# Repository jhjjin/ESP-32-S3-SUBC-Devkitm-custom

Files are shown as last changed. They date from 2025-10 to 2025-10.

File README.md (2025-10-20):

# ⚡ ESP32-S3 USB-C DevkitM Custom Board  
Custom **ESP32-S3 (ESP32-S3-MINI-1-N8)** development board designed from scratch in **Altium Designer 25.8.1**, featuring USB-C connectivity, FT231X UART bridge, ESD protection, and a 4-layer impedance-controlled PCB verified for **JLCPCB** manufacturing standards.  

---

## 🧩 Overview

- A fully custom ESP32-S3-MINI-1-N8 dev board built as a learning and portfolio project.  
- Designed and validated for manufacturability, signal integrity, and professional layout discipline.
--- 
Key specs:
- ✅ USB-C interface (Molex I/O connector)
- ✅ FTDI FT231XQ-R USB-UART bridge  
- ✅ Littelfuse AQ3045-01ETG (ESD/TVS Protection)
- ✅ Low-dropout regulator with ESR 20 µF input cap  
- ✅ Differential pair routing for USB 2.0  
- ✅ Variant setup for NF (DNP) parts  
- ✅ JLCPCB 4-Layer Stackup (JLC04161H-3313)

---

## 🛠️ Design Tools & Environment
| Tool | Version | Purpose |
|---|---|---|
| **Altium Designer** | 25.8.1 | Schematic, PCB, DRC |
| **ViewMate** | 11.14 | Gerber Verification |
| **SnapEDA / 3D ContentCentral** | – | STEP Models / Footprints |
| **JLCPCB Calculator** | – | Impedance Matching |

---

## 📐 PCB Stackup
| Layer | Type | Notes |
|---|---|---|
| **L1** | Signal (Top) | High-speed USB / MCU routing |
| **L2** | GND Plane | Solid ground reference |
| **L3** | Power Plane | +3V3 / +5V islands |
| **L4** | Signal (Bottom) | GPIO, UART, LED, test traces |

📏 **Stackup:** JLC04161H-3313 (1.6 mm FR-4)  
🎯 **USB 90 Ω diff / 50 Ω single** controlled impedance

---

## ⚙️ Main Components

| Function | Part | Supplier | LCSC Part No |
|---|---|---|---|
| MCU | ESP32-S3-MINI-1-N8 | ESPRESSIF | **C2913206** |
| USB-UART | FT231XQ-R | FTDI | **C3212159** |
| ESD Protection | AQ3045-01ETG | Littelfuse | **C3710326** |
| Regulator | TL1963A-33DCYR (3.3 V LDO) | Texas Instruments | **C1812626** |
| LED (Green) | VLMG1500-GS08 | Vishay | **C5111404** |
| LED (Red) | VLMS1500-GS08 | Vishay | **C5111370** |
| Cap (100 nF, 50 V) | CL05B104KB54PNC | Samsung | **C307331** |
| Cap (4.7 µF, 16 V) | CL05A475MO5NUNC | Samsung | **C318563** |
| Resistor (1 kΩ) | RC0402FR-071KL | Yageo | **C106023** |
| Resistor (4.7 kΩ) | RC0402FR-074K7L | Yageo | **C105871** |
| Resistor (5.1 kΩ) | RC0402FR-075K1L | Yageo | **C1447745** |
| Resistor (10 kΩ) | RC0402FR-0710KL | Yageo | **C1444807** |
| Jumper Header (2-pin) | FTS-102-01-F-S | Samtec | **C6045317** |
| Jumper Header (3-pin) | FTS-103-01-F-S | Samtec | **C3333578** |
| Shunt | M50-1920005 | Harwin | **C6985646** |
| USB-C Connector | 217179-0001 | Molex | **C3197684** |
| Transistor | SS8050-G | Comchip | **C21406** |
| Diode (TVS) | AQ3045-01ETG | Littelfuse | **C3710326** |

---

## 🧭 Schematic Overview
```
USB-C (Power / Data)
     │
[FT231X UART Bridge]
     │
ESP32-S3-MINI-1-N8 ←→ Boot / Reset / LEDs / Headers
     │
[LDO Regulator]
     │
+3V3 / +5V
```
---

---

## 🔍 Build Notes & Troubleshooting

### ⚡ Common Design Challenges
| Issue | Cause | Fix |
|---|---|-----|
| GND recognized as +3V3 | Power port misconnection | Disconnect and redraw from `GND` port |
| FTDI clearance too tight | Dense routing | Define `Room('FTDI')` and set clearance 6 mil |
| USB diff pair warning | Width/gap mismatch | Apply `DIFF90` rule (6.03 mil / 8 mil) |
| “Footprint not found” (J6) | Library mismatch | Re-link footprint and `Design ▸ Update PCB` |
| Silk-to-mask errors | Fabrication tolerance | Set `Silk to Mask = 5 mil` per JLC spec |
| 3D misalignment | STEP origin offset | `3D Body ▸ Align Face with Body` → `Set Reference Center` |

---

### 🧱 PCB Layout Highlights
- **Via:** Ø 24 mil / hole 12 mil  
- **USB diff pairs:** 6.03 mil width, 8 mil spacing  
- **Power tracks:** 15 mil width  
- **GND stitching vias:** around USB and RF areas  
- **Polygon pour:** direct connect for +3V3, thermal for GND  

## 🖼️ Hardware Preview

<p align="center">
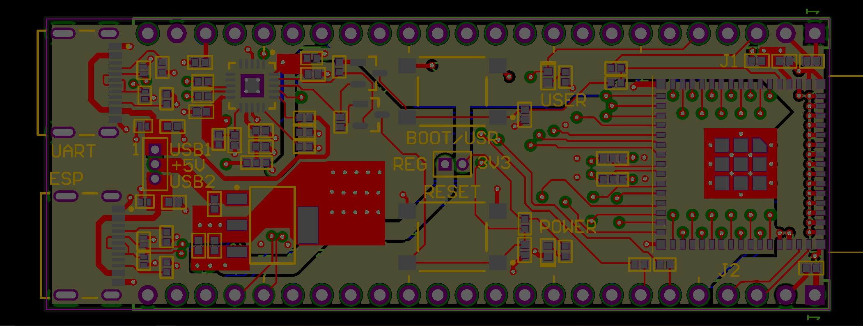
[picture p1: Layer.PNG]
PCB Layout Overview
  
</p>

| 3D Front | 3D Back |
|:---:|:---:|
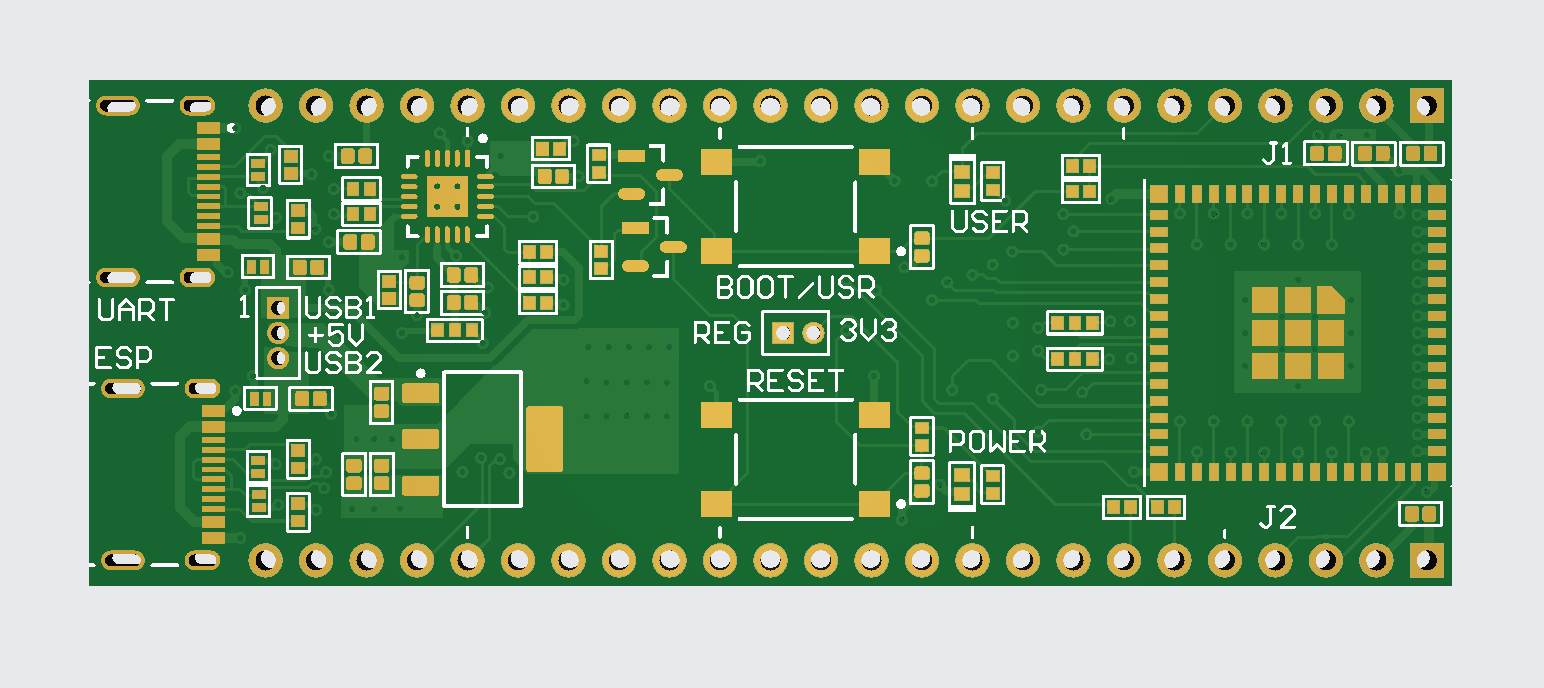
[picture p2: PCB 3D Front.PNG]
3D Front View
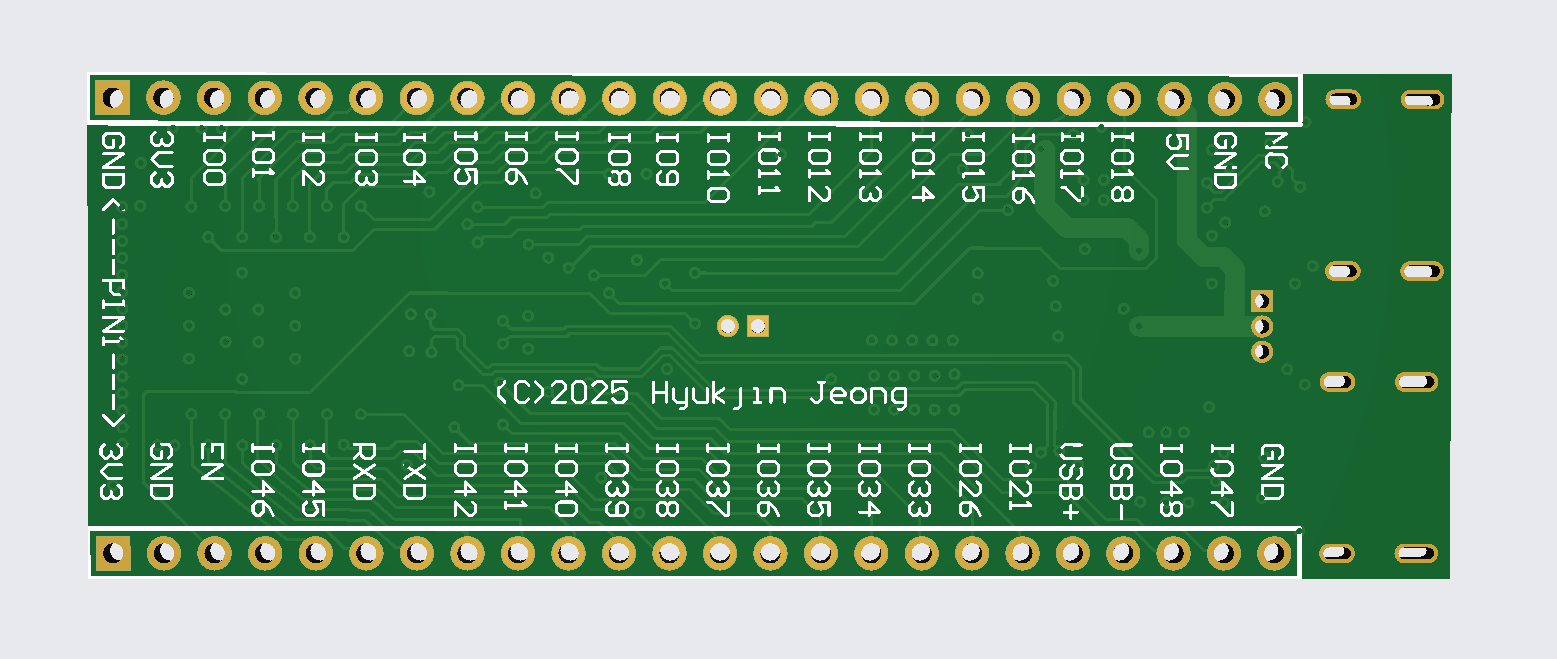
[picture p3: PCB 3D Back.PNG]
3D Back View
|  |  |

> **Figure:** PCB layout (Layer) and 3D render previews for the custom ESP32-S3 USB-C DevkitM board.

---
---

## 📦 Fabrication Outputs

The project includes full manufacturing and assembly documentation for **JLCPCB** and other PCB assembly vendors.

### 🧾 Bill of Materials (BOM)
| Field | Example |
|:---|:---|
| **Component Count** | 38 unique parts (Samsung, Yageo, FTDI, Espressif, TI, etc.) |
| **Main ICs** | ESP32-S3-MINI-1-N8, FT231XQ-R, TL1963A-33DCYR |
| **Passive Parts** | 0402 Capacitors & Resistors (Yageo / Samsung) |
| **ESD / Protection** | Littelfuse AQ3045-01ETG |
| **Connectors** | Molex USB-C (217179-0001), Samtec Headers (FTS-103-01-F-S / FTS-102-01-F-S) |
| **LEDs** | Vishay VLMG1500-GS08 (Green), VLMS1500-GS08 (Red) |
| **Supplier Integration** | LCSC + DigiKey references with cross-checked MPNs |

🧩 The BOM is exported directly from **Altium Designer 25.8.1**, containing:
- Description, Designator, Footprint, Quantity, Manufacturer, MPN, LCSC / DigiKey number  
- All capacitors and resistors use **0402 metric footprint**  
- Variant configuration for **NF (Not Fitted)** parts included  

---

### 📍 Pick & Place (Component Position)
| Field | Example Data |
|:---|:---|
| **Coordinates** | X/Y in mils (Altium standard) |
| **Rotation** | 0°, 90°, 180°, 270° |
| **Layers** | TopLayer / BottomLayer |
| **Included Fields** | Designator, Comment, Layer, Footprint, Center-X, Center-Y, Rotation, Description |

---
## 🧠 Learnings & Focus

- Real-world PCB stackup and impedance control

- Rule-based design approach (Component, Clearance, DiffPairs)

- Synchronizing schematic ↔ PCB libraries

- DRC-driven layout verification

- Preparation of Gerber, BOM, Pick & Place, and PDF documentation

---

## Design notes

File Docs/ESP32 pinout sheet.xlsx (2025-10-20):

1 | GND_01
2 | GND_02
3 | 3V3
4 | GPIO0/RTC_GPIO0
5 | GPIO1/RTC_GPIO1/TOUCH1/ADC1_CH0
6 | GPIO2/RTC_GPIO2/TOUCH2/ADC1_CH1
7 | GPIO3/RTC_GPIO3/TOUCH3/ADC1_CH2
8 | GPIO4/RTC_GPIO4/TOUCH4/ADC1_CH3
9 | GPIO5/RTC_GPIO5/TOUCH5/ADC1_CH4
10 | GPIO6/RTC_GPIO6/TOUCH6/ADC1_CH5
11 | GPIO7/RTC_GPIO7/TOUCH7/ADC1_CH6
12 | GPIO8/RTC_GPIO8/TOUCH8/ADC1_CH7/SUBSPICS1
13 | GPIO9/RTC_GPIO9/TOUCH9/ADC1_CH8/FSPIHD/SUBSPIHD
14 | GPIO10/RTC_GPIO10/TOUCH10/ADC1_CH9/FSPICS0/FSPIIO4/SUBSPICS0
15 | GPIO11/RTC_GPIO11/TOUCH11/ADC2_CH0/FSPID/FSPIIO5/SUBSPID
16 | GPIO12/RTC_GPIO12/TOUCH12/ADC2_CH1/FSPICLK/FSPIIO6/SUBSPICLK
17 | GPIO13/RTC_GPIO13/TOUCH13/ADC2_CH2/FSPIQ/FSPIIO7/SUBSPIQ
18 | GPIO14/RTC_GPIO14/TOUCH14/ADC2_CH3/FSPIWP/FSPIDQS/SUBSPIWP
19 | GPIO15/RTC_GPIO15/U0RTS/ADC2_CH4/XTAL_32K_P
20 | GPIO16/RTC_GPIO16/U0CTS/ADC2_CH5/XTAL_32K_N
21 | GPIO17/RTC_GPIO17/U1TXD/ADC2_CH6
22 | GPIO18/RTC_GPIO18/U1RXD/ADC2_CH7/CLK_OUT3
23 | USB_D-/RTC_GPIO19/GPIO19/U1RTS/ADC2_CH8/CLK_OUT2
24 | USB_D+/RTC_GPIO20/GPIO20/U1CTS/ADC2_CH9/CLK_OUT1
25 | GPIO21/RTC_GPIO21
26 | GPIO26/SPICS1
27 | GPIO47/SPICLK_P_DIFF/SUBSPICLK_P_DIFF
28 | GPIO33/SPIIO4/FSPIHD/SUBSPIHD
29 | GPIO34/SPIIO5/FSPICS0/SUBSPICS0
30 | GPIO48/SPICLK_N_DIFF/SUBSPICLK_N_DIFF
31 | GPIO35/SPIIO6/FSPID/SUBSPID
32 | GPIO36/SPIIO7/FSPICLK/SUBSPICLK
33 | GPIO37/SPIDQS/FSPIQ/SUBSPIQ
34 | GPIO38/FSPIWP/SUBSPIWP
35 | MTCK/GPIO39/CLK_OUT3/SUBSPICS1
36 | MTDO/GPIO40/CLK_OUT2
37 | MTDI/GPIO41/CLK_OUT1
38 | MTMS/GPIO42
39 | U0TXD/GPIO43/CLK_OUT1
40 | U0RXD/GPIO44/CLK_OUT2
41 | GPIO45
42 | GND
43 | GND
44 | GPIO46
45 | EN
46 | GND_46
47 | GND_47
48 | GND_48
49 | GND_49
50 | GND_50
51 | GND_51
52 | GND_52
53 | GND_53
54 | GND_54
55 | GND_55
56 | GND_56
57 | GND_57
58 | GND_58
59 | GND_59
60 | GND_60
61 | GND_61
62 | GND_62
63 | GND_63
64 | GND_64
65 | GND_65
66 | GND_66
67 | GND_67
68 | GND_68
69 | GND_69
70 | GND_70
71 | GND_71
72 | GND_72
73 | GND_73

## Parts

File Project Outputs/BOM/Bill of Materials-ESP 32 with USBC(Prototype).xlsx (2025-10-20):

Comment | Description | Designator | Footprint | LibRef | Quantity | LCSC Part Number | Manufacturer | Manufacturer Part Number | Supplier | Supplier Part Number
100nF, 50V | CAP CER 0.1UF 50V X7R 0402 | C1, C3, C4, C5, C6, C8, C9, C10, C15 | CAPC1005X65N | CL05B104KB54PNC | 9 | C307331 | Samsung Electro-Mechanics | CL05B104KB54PNC | DigiKey | 1276-CL05B104KB54PNCCT-ND
4u7, 16V | CAP CER 4.7UF 16V X5R 0402 | C2, C11 | CAPC1005X65N | CL05A475MO5NUNC | 2 | C318563 | Samsung Electro-Mechanics | CL05A475MO5NUNC | DigiKey | 1276-6836-1-ND
10uF, 10V | CAP CER 10UF 10V X5R 0402 | C12, C13, C14 | CAPC1005X65N | CL05A106MP8NUB8 | 3 | C307415 | Samsung Electro-Mechanics | CL05A106MP8NUB8 | DigiKey | 1276-6830-6-ND
1uF, 35V | CAP CER 1UF 35V X5R 0402 | C16 | CAPC1005X65N | CL05A105KL5NRNC | 1 | C307413 | Samsung Electro-Mechanics | CL05A105KL5NRNC | DigiKey | 1276-6796-6-ND
GREEN | LED YLW-GRN 0402 SMD | D1 | LED0402G | VLMG1500-GS08 | 1 | C511404 | Vishay | VLMG1500-GS08 | DigiKey | VLMG1500-GS08CT-ND
RED | LED RED 0402 SMD | D2 | LED0402R | VLMS1500-GS08 | 1 | C511370 | Vishay | VLMS1500-GS08 | DigiKey | VLMS1500-GS08CT-ND
AQ3045-01ETG | TVS DIODE 5.3VWM 12VC SOD882 | D3, D4, D5, D6, D7, D8 | SOD882 | AQ3045-01ETG | 6 | C3710326 | Littelfuse | AQ3045-01ETG | DigiKey | F9321CT-ND
22-28-4245 | CONN HEADER VERT 24POS 2.54MM | J1, J2 | HDR_1X24_2.54MM | 22-28-4245 | 2 | C7145888 | Molex | 22-28-4245 | DigiKey | 900-0022284245-ND
217179-0001 | CONN RCP USB2.0 TYP C 24P SMD RA | J3, J4 | FP-2171790001-MFG | 217179-0001 | 2 | C3197684 | Molex | 217179-0001 | DigiKey | 900-2171790001CT-ND
FTS-103-01-F-S | CONN HEADER VERT 3POS 1.27MM | J5 | HDR_1X3_1.27MM | FTS-103-01-F-S | 1 | C3333578 | Samtec | FTS-103-01-F-S | DigiKey | 612-FTS-103-01-F-S-ND
FTS-102-01-F-S | CONN HEADER VERT 2POS 1.27MM | J6 | HDR_1X2_1.27MM | FTS-102-01-F-S | 1 | C6045317 | Samtec | FTS-102-01-F-S | DigiKey | SAM15176-ND
M50-1920005 | CONN SHUNT 1.27MM RED | LINK1, LINK2 |  | M50-1920005 | 2 | C6985646 | Harwin | M50-1920005 | DigiKey | 952-1727-ND
SS8050-G | TRANS NPN 25V 1.5A SOT-23-3 | Q1, Q2 | FP-SS8050-G-IPC_B | SS8050-G | 2 | C164886 | Comchip | SS8050-G | DigiKey | 641-1790-1-ND
0R | RES 0 OHM JUMPER 1/16W 0402 | R1, R5, R8, R19, R20, R23, R24 | RESC1005X37N | RC0402JR-070RL | 7 | C60485 | Yageo Group | RC0402JR-070RL | DigiKey | 311-0.0JRCT-ND
1K | RES 1K OHM 1% 1/16W 0402 | R3, R4 | RESC1005X37N | RC0402FR-0710KL | 2 | C106235 | Yageo Group | RC0402FR-0710KL | DigiKey | 311-10.0KLRCT-ND
27R | RES 27 OHM 1% 1/16W 0402 | R6, R7, R21, R22 | RESC1005X37N | RC0402FR-0727RL | 4 | C138021 | Yageo Group | RC0402FR-0727RL | DigiKey | YAG3086CT-ND
4k7 | RES 4.7K OHM 1% 1/16W 0402 | R10 | RESC1005X37N | RC0402FR-074K7L | 1 | C105871 | Yageo Group | RC0402FR-074K7L | DigiKey | 311-4.7KLRCT-ND
5k1 | 62.5mW Thick Film Resistors 50V RES SMD 5.1K OHM 1% 1/16W 0402±100ppm/℃ ±1% 5.1kΩ 0402 Chip Resistor - Surface Mount ROHS | R11, R12, R14, R15 | RESC1005X37N | AC0402FR-075K1L | 4 | C144745 | Yageo Group | AC0402FR-075K1L | DigiKey | YAG3503CT-ND
10k | RES SMD 10K OHM 1% 1/16W 0402 | R13, R16, R17, R18 | RESC1005X37N | AC0402FR-0710KL | 4 | C144807 | Yageo Group | AC0402FR-0710KL | DigiKey | YAG3436CT-ND
PTS645SH50SMTR92LFS | SWITCH TACTILE SPST-NO 0.05A 12V | SW1, SW2 | FP-PTS645SH50SMTR92LFS-MFG | PTS645SH50SMTR92LFS | 2 | C221869 | C&K Components | PTS645SH50SMTR92LFS | DigiKey | CKN9085CT-ND
ESP32-S3-MINI-1-N8 | SMD Module, ESP-32-S3FN8, 8 mb Sp | U1 | XCVR_ESP32-S3-MINI-1-N8 | ESP32-S3-MINI-1-N8 | 1 | C2913206 | Espressif Systems | ESP32-S3-MINI-1-N8 | DigiKey | 5407-ESP32-S3-MINI-1-N8CT-ND
FT231XQ-R | IC USB SERIAL FULL UART 20QFN | U2 | FP-QFN-20-IPC_B | FT231XQ-R | 1 | C132159 | FTDI | FT231XQ-R | DigiKey | 768-1128-1-ND
TL1963A-33DCYR | IC REG LIN 3.3V 1.5A SOT-223-4 | U3 | DCY0004A_N | TL1963A-33DCYR | 1 | C181262 | Texas Instruments | TL1963A-33DCYR | DigiKey | 296-24897-1-ND

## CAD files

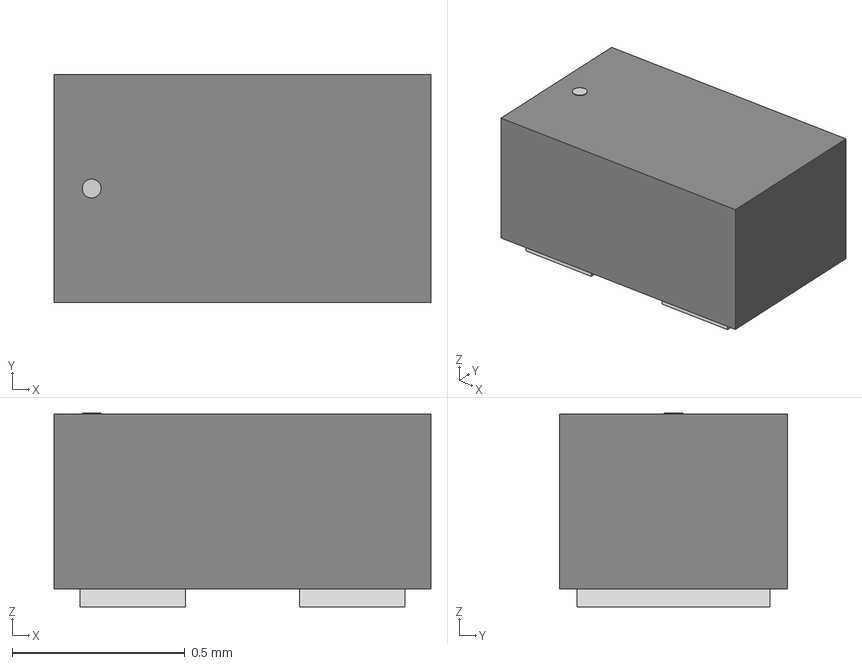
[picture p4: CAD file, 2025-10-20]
3D/AQ3045-01ETG.step
1.09 x 0.66 x 0.561 mm

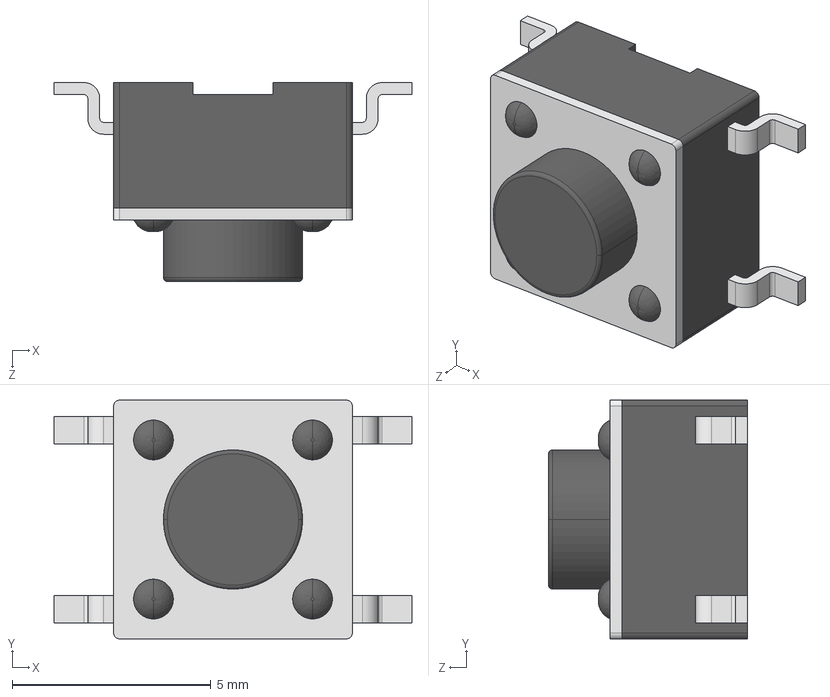
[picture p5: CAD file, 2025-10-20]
3D/User Library-PTS645SL50SMTR92-LFS.STEP
9.00 x 6.00 x 5.00 mm

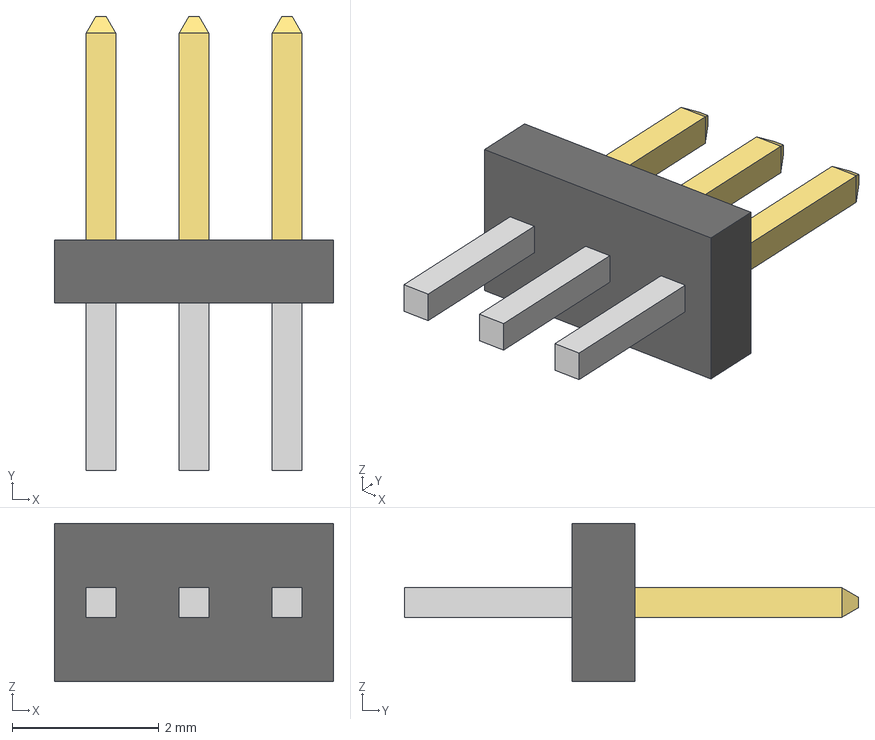
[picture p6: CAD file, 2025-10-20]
3D/FTS-103-01-F-S.stp
3.81 x 6.20 x 2.16 mm
FTS-103-01-F-S_body
FTS-103-01-F-S_pins1
FTS-103-01-F-S_pins2

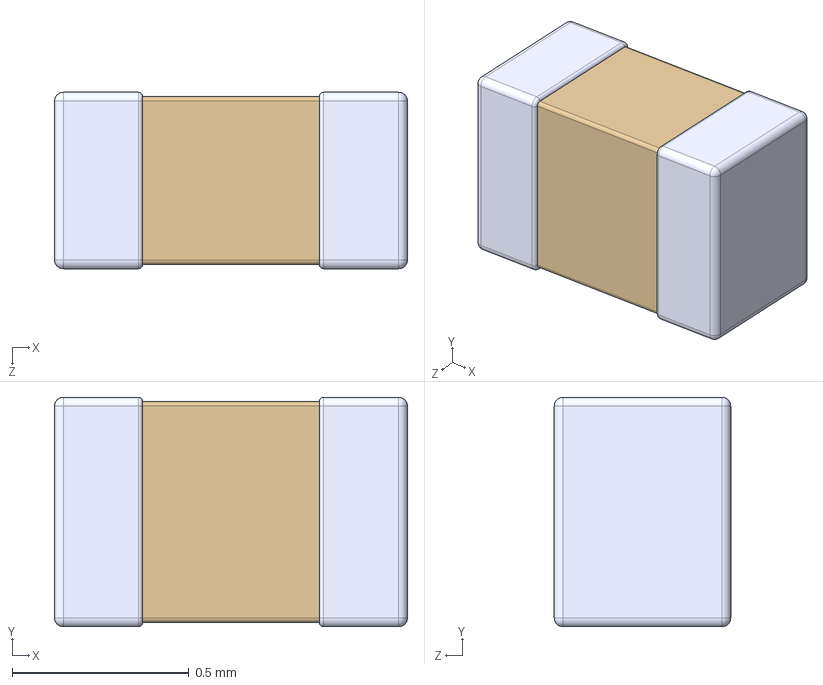
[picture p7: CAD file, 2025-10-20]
3D/CL05A105KL5NRNC--3DModel-STEP-56544.STEP
1.00 x 0.65 x 0.5 mm

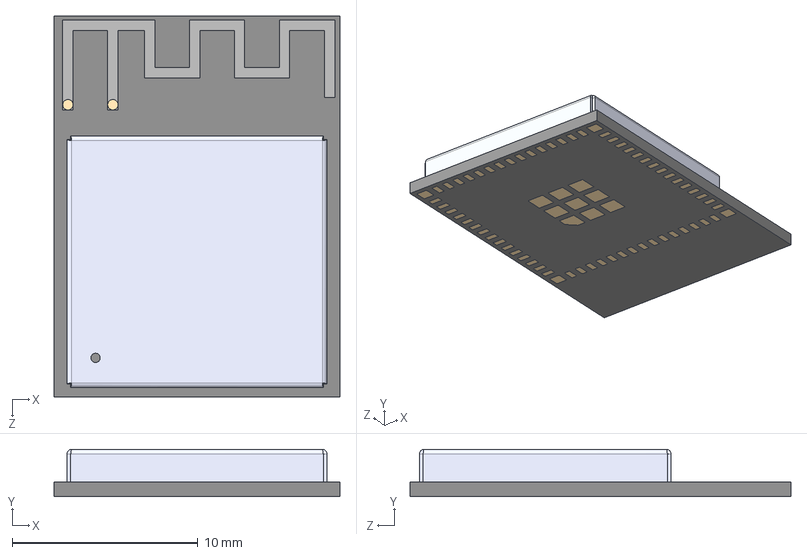
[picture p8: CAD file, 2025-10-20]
3D/ESP32-S3-MINI-1-N8--3DModel-STEP-510211.STEP
15.4 x 2.55 x 20.5 mm

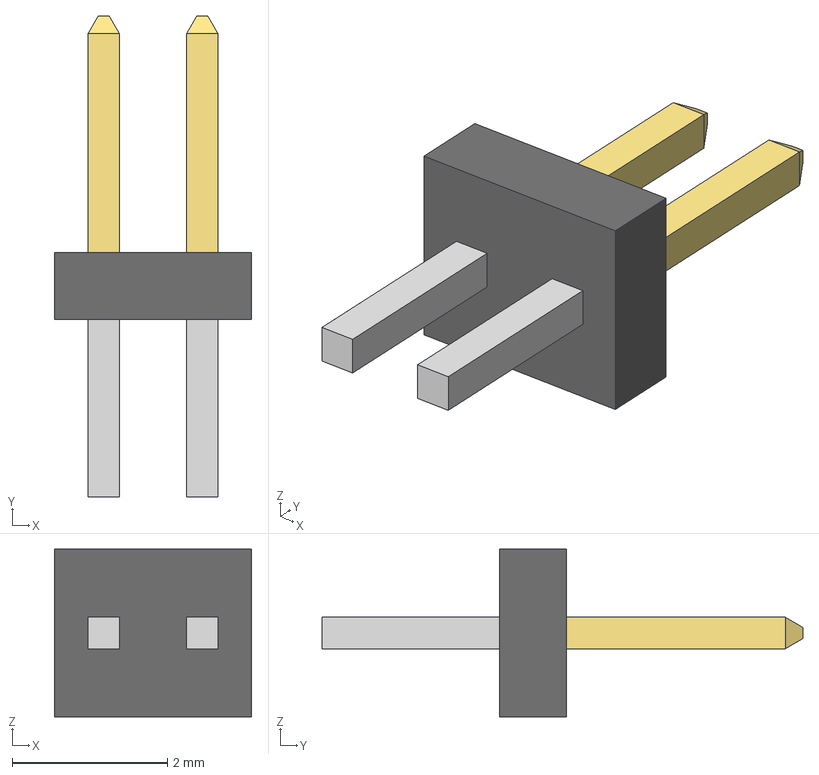
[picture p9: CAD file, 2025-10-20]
3D/FTS-102-01-F-S.stp
2.54 x 6.20 x 2.16 mm
FTS-102-01-F-S_body
FTS-102-01-F-S_pins1
FTS-102-01-F-S_pins2

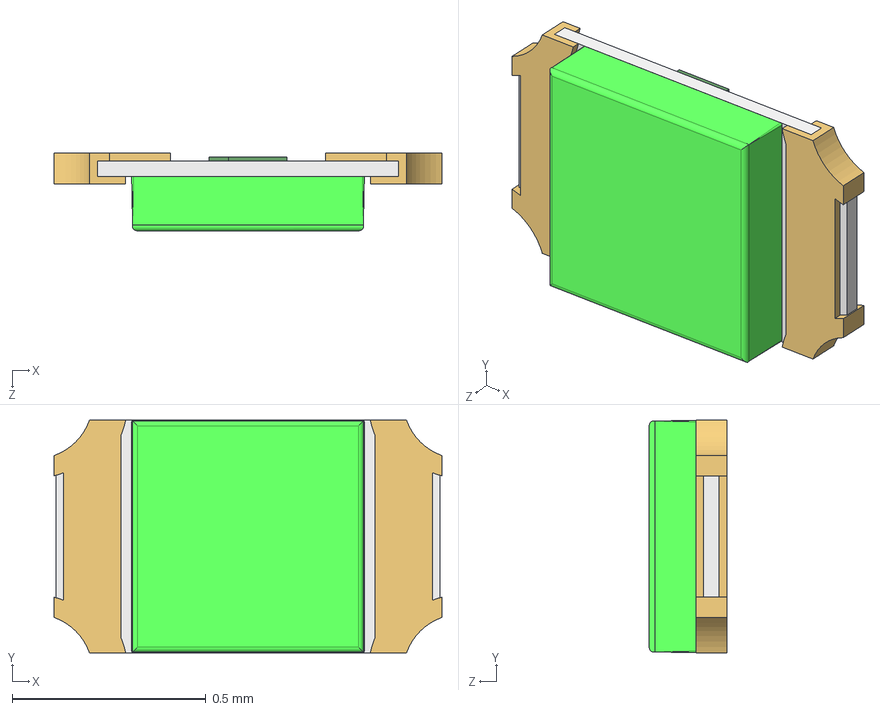
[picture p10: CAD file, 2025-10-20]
3D/User Library-LED_1006_G.STEP
1.00 x 0.6 x 0.2 mm
Grⁿn
Cut005_(Mirror_#1)

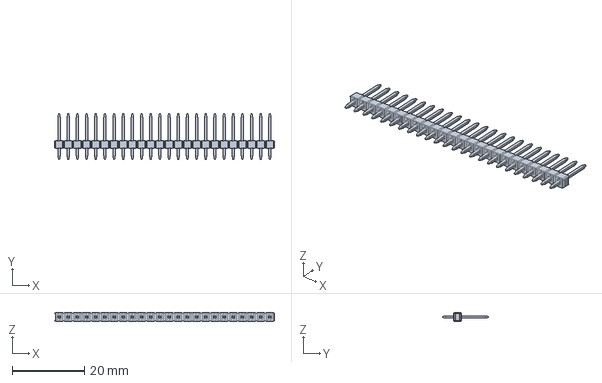
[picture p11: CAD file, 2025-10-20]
3D/0022284245.stp
61.0 x 12.8 x 2.49 mm

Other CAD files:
3D/User Library-LED_1006_R.STEP

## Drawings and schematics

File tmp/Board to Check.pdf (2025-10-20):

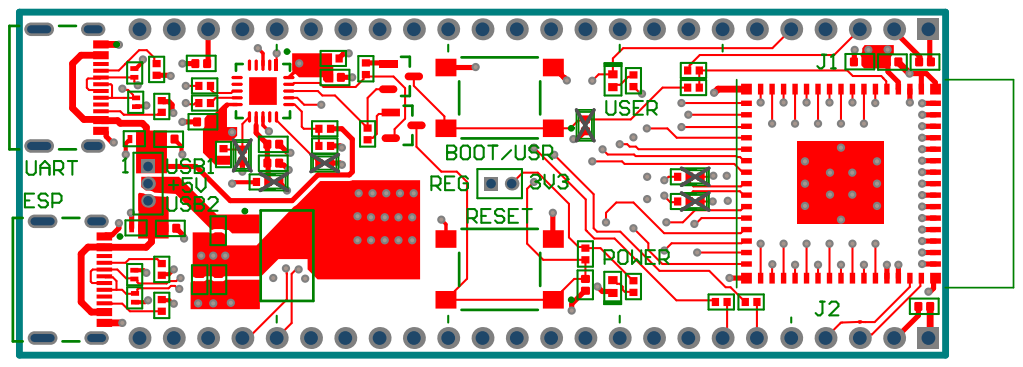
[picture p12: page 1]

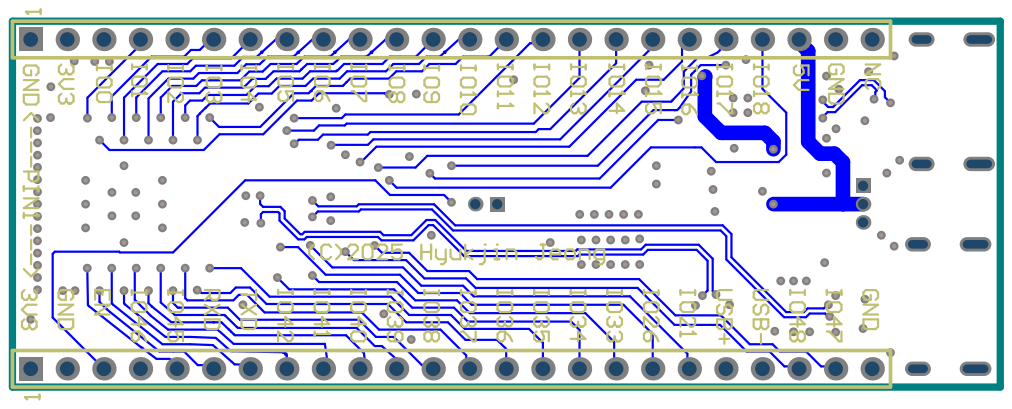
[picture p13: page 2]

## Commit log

2025-10-20 Revise README for ESP32-S3 DevkitM details
    Updated README to enhance clarity and detail about the ESP32-S3 USB-C DevkitM custom board, including specifications, design tools, PCB stackup, main components, schematic overview, build notes, and 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
2025-10-20 Enhance README with schematic and 3D PCB images
    Updated images and added 3D views in the README.
2025-10-20 Add example images for PCB layout and 3D views
    Updated README to include example images for PCB layout and 3D views.
2025-10-20 Revise README for fabrication outputs and BOM details
    Updated the README to include detailed fabrication outputs and a bill of materials (BOM) section.
2025-10-20 Upload 3D folder (STEP files)
    [0022284245.stp, AQ3045-01ETG.step, CL05A105KL5NRNC--3DModel-STEP-56544.STEP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]
2025-10-20 Upload Doc folder
    [ESP32 pinout sheet.xlsx]
2025-10-20 Upload Project Outputs for ESP 32
    [BOM.xlsx, Bill of Materials-ESP 32 with USBC(Prototype).xlsx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]
2025-10-20 Upload Project Outputs folder
    [BOM.xlsx, Bill of Materials-ESP 32 with USBC(Prototype).xlsx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]

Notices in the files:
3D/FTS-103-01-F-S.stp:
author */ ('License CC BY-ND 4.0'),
